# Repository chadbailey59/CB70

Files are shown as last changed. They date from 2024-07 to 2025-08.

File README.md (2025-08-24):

# CB70: A Split, Staggered Wireless Keyboard

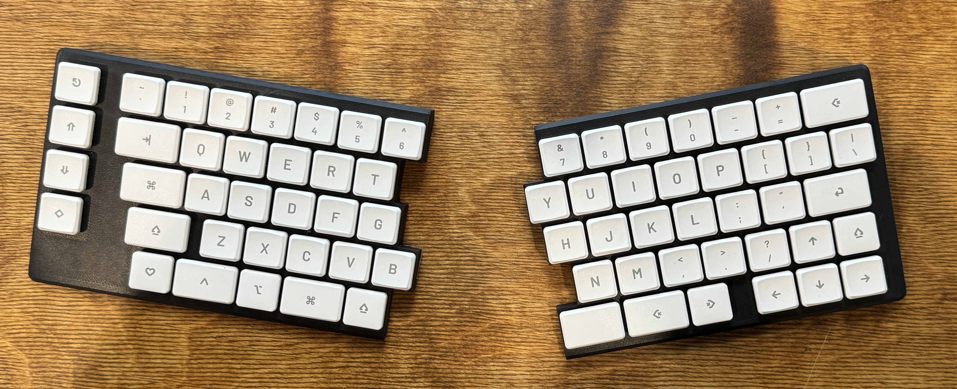
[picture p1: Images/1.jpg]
Low-Profile Choc Version


- Supports MX and Choc switches
- Dual-wireless, powered by Nice!Nano v2's and ZMK
- Compatible with lots of popular keysets

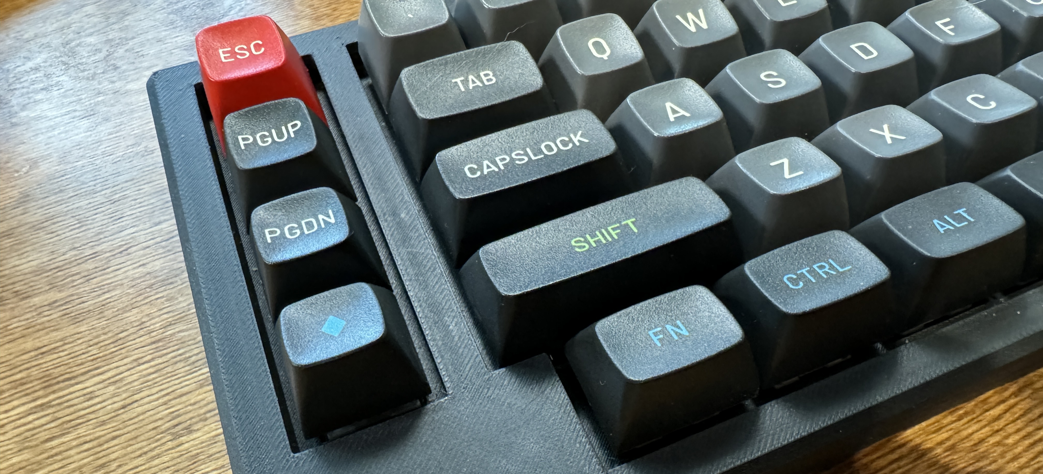
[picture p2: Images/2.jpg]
MX Version


Why CB70? It's my initials, and it used to be a 70-key layout. When I deleted a key, changing the name to The Joke Number just seemed too obvious.

## What's Available

- KiCAD files for the combo MX/Choc PCBs in `/PCB`
- [Keyboard Layout Editor](http://www.keyboard-layout-editor.com/) JSON for the MX and Choc versions in `/KLE`
- Config files for the ZMK firmware in `/ZMK`, and pre-compiled firmware in `/Firmware`
- OnShape docs for three different cases: [MX](https://cad.onshape.com/documents/61077a70c0807a2f741d218a/w/b756240a5bc81a242d3100ae/e/06f8d761157dde9586b0a508), [Choc](https://cad.onshape.com/documents/518ea40d790487622d23318b/w/b5c85f466e1f1d2c95445d69/e/3acfa7d78165eaa4fb25c29e), and [Choc Slim](https://cad.onshape.com/documents/839a1d1e7ccef3f6cb852ad6/w/885d6dd90bac1c92721256f6/e/4149e8558c641b31c0ba8e37)
- STL files for the 3 different case styles in `/Case`

### Update 2025-08-24: The Dongle Variant

ZMK recently added support for [dongles!](https://zmk.dev/docs/development/hardware-integration/dongle) There are now two versions of the firmware and ZMK source. The `non-dongle` folder is the traditional CB70, with two nice!nanos—one for the left half, one for the right. The `dongle` version actually requires _three_ nice!nanos (or whatever boards you're using): Two for the left and right halves, and one for the 'dongle'.

The main benefit of the dongle version (for me) is that it's easier to switch the whole keyboard to another computer by just plugging in the dongle.

## The Philosophy

The key layout is based around something I've been honing for almost five years now. I've tried a few different ortho/ergo layouts, but contrary to what the internet says, they always slow me down way too much. Meanwhile, I use this at my desk, I still use my MacBook Pro's built-in keyboard a lot, and I average 110-120 WPM on both.

A few thoughts on the layout:

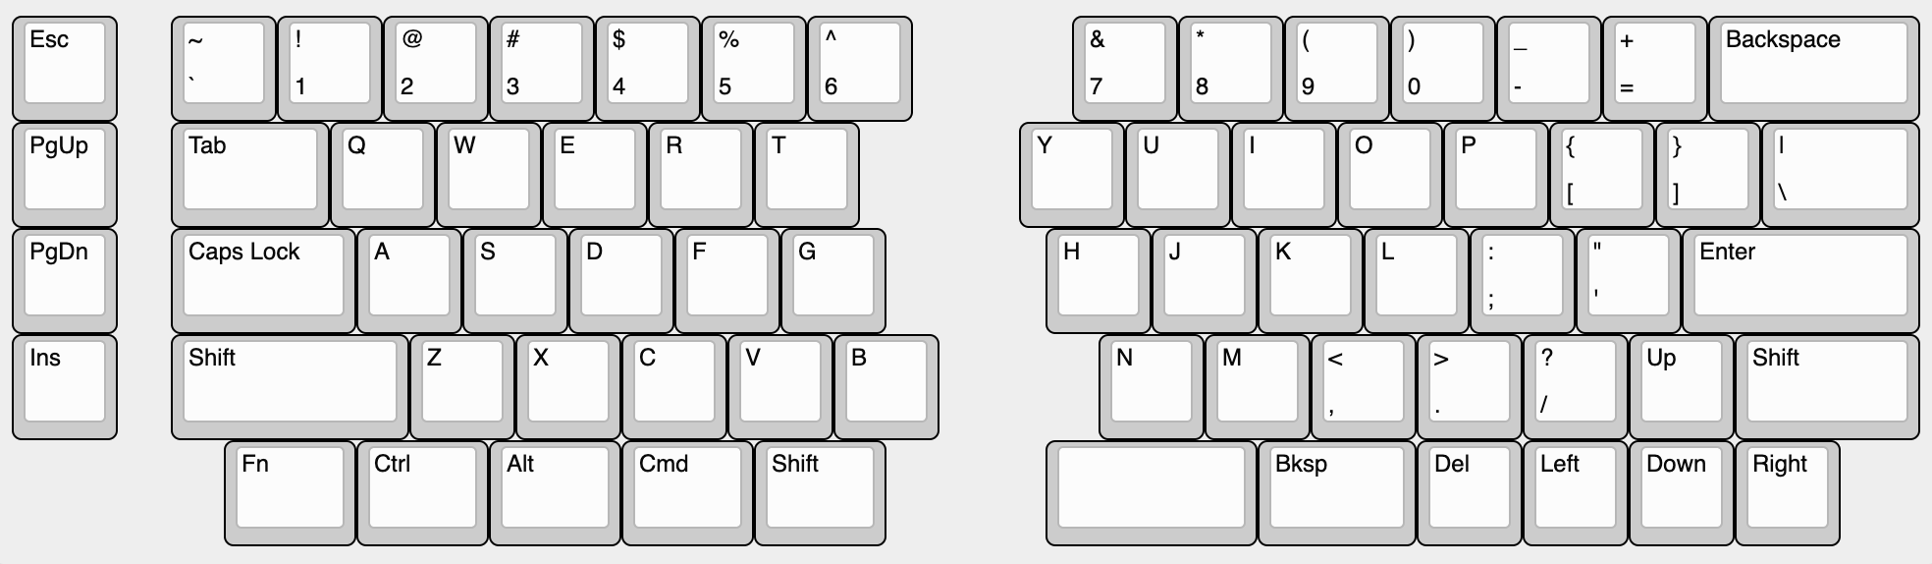
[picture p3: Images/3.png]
Key Layout


I wanted to maintain parity between my keyboard and my MacBook Pro's keyboard as much as possible, so I don't do much with ZMK itself. Rather, I use [Karabiner-elements](https://karabiner-elements.pqrs.org/) to make many of these 'tricks' work for both my custom keyboard and my MacBook Pro.

I've found I never use my left thumb for the space bar, so I placed a Shift key where my left thumb naturally falls. I fell in love with this almost immediately, and it's the first thing I miss when typing on my MacBook Pro. I've tried a few different Karabiner-elements hacks to attempt to replicate this for the MBP's built-in space bar, but none of them work that well.

I use the Caps Lock key as an additional Command key with my left pinky, which you'll see in the Choc keyset. That's remapped in Karabiner-elements so it works both places.

The bottom-left key is a "Function" key, but I use a Karabiner-elements complex modification called "Map Function to Hyper when held" to give me a bunch of custom shortcuts. I can't figure out how to share that directly here.

The bottom-right Backspace key is remapped to Option-Backspace, which deletes a word. This is maybe my single favorite thing I've ever done on a computer. If I'm writing in Slack and realize I want to reword the last few words I typed, it's a super quick way to delete a word at a time.

The left column gives me a dedicated Esc key, and the other three are remapped to volume up/down, and a play/pause key.

## Building Your Own

### Switches and Stabilizers

You'll need at least 69 switches, either 2-pin MX or Choc. If you use MX switches, you'll need 4 plate-mount stabilizers, [such as these](https://www.amazon.com/DUROCK-Stabilizer-Keyboard-Stabilizers-Compatible/dp/B0CRRHP9MY/). The Choc version doesn't use any stabilizers.

### Keycaps

You can get the same Choc keycaps you see in the picture from [FK Caps' Custom Shop](https://fkcaps.com/custom/1VP7N2) if you want.

For Choc switches, you'll need 60 1u keycaps, and 9 1.5u keycaps.

For MX switches, you should be able to get by with a pretty standard TKL or 70% keyset (that's by design). The only 'weird' keys are:

- 1.75u right Shift key
- 1.5u Backspace key in the bottom row
- 2u space bar
- 1.25u Shift key for your left thumb

The pictured MX version is the [MT3 Susuwatari keyset](https://drop.com/buy/drop-matt3o-mt3-susuwatari-custom-keycap-set?defaultSelectionIds=952681) from Drop, with the Base kit covering everything except the 2u space bar (which I added from the "Spacebars" kit).

### Other Supplies

- 12 [M3 x 4mm heat set inserts](https://www.amazon.com/gp/product/B09MCWTBCC)
- 12 M3 x 8mm screws
- 69 [1N4148 diodes](https://www.amazon.com/gp/product/B07Q4F3Y5W/ref=ppx_yo_dt_b_search_asin_title?ie=UTF8&psc=1)
- 2 [3.7V batteries with JST-PHR-02 connectors](https://www.amazon.com/gp/product/B08VRYS8FT)
- 6 [JST 2.0mm connectors for the PCB](https://www.amazon.com/Taiss-Connector-Housing-Connectors-F-066-580PCS/dp/B0BHT1FQGY). The PCBs are spaced for the 2mm JST connectors, which are sometimes also called JST-PHR-02, like on the linked batteries.
- 2 nice!nano v2 boards
- [These round pin headers](https://www.amazon.com/Uxcell-a14081900ux0270-Single-Straight-Header/dp/B012ACSO4Y) to socket the nice!nanos
- Most people use diode legs to socket the nice!nanos, but if you want nicer pins, [these are the only ones I've found](https://www.amazon.com/dp/B0CKYKRSZ6?ref=ppx_yo2ov_dt_b_product_details&th=1).
- Some [push button switches](https://www.amazon.com/dp/B085SWHFMK?psc=1&ref=ppx_yo2ov_dt_b_product_details) and
  [SPST slide switches](https://www.amazon.com/dp/B09R43HCY3?psc=1&ref=ppx_yo2ov_dt_b_product_details) for reset and power. These particular ones can be wired to JST connectors for case mounting, or soldered directly into the PCB for low-profile setups.

### Assembly

Assembly should be pretty straightforward if you've built a keyboard before. The PCBs are marked for diode orientation. You'll want to make sure to install all of the diodes and the nice!nano sockets before installing any of the keyswitches. I also needed to snip the nice!nano socket legs flush with the PCB so the keyswitches mounted flat.

See the ZMK instructions for using GitHub actions to build the firmware yourself if you want to edit the keymaps.

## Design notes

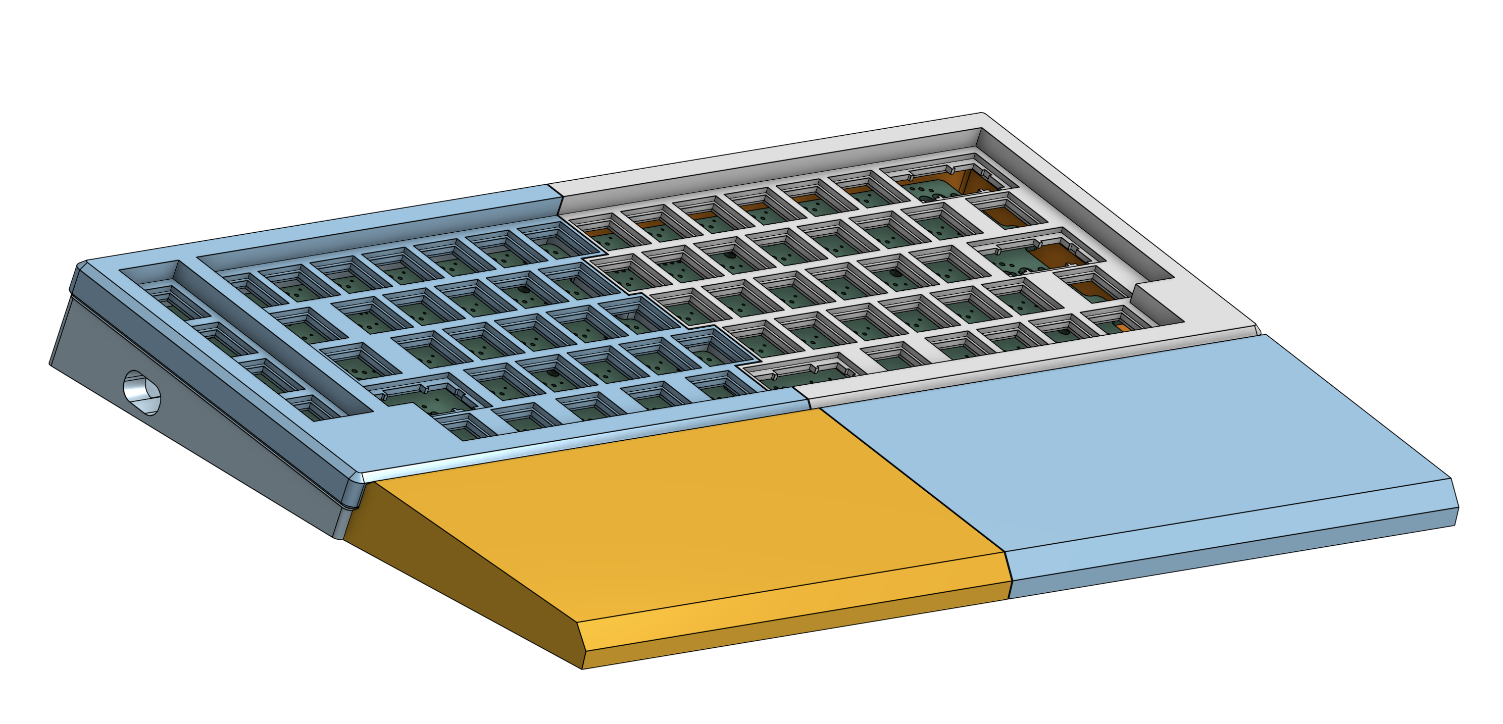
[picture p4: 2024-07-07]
Case/MX/pic.png

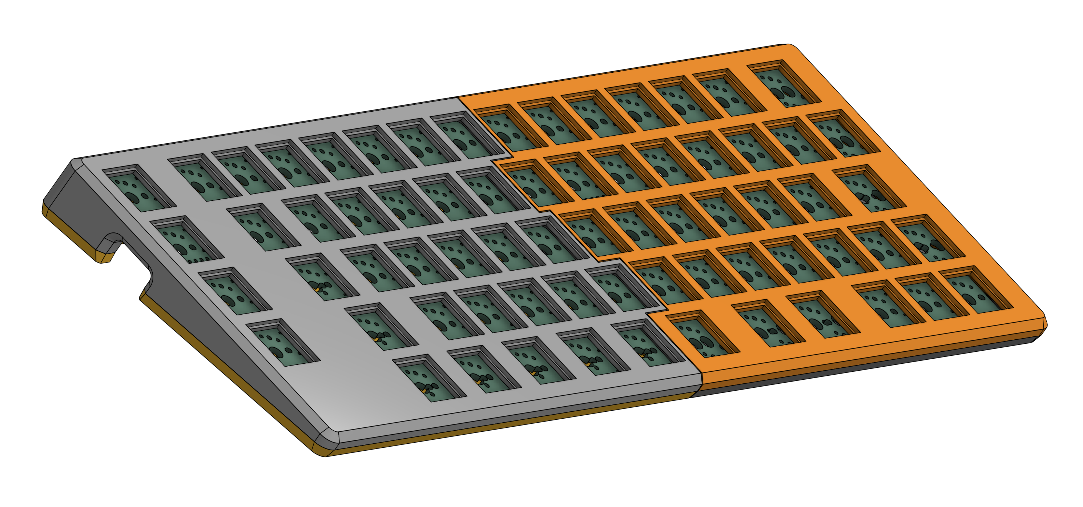
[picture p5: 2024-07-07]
Case/Choc-Slim/pic.png

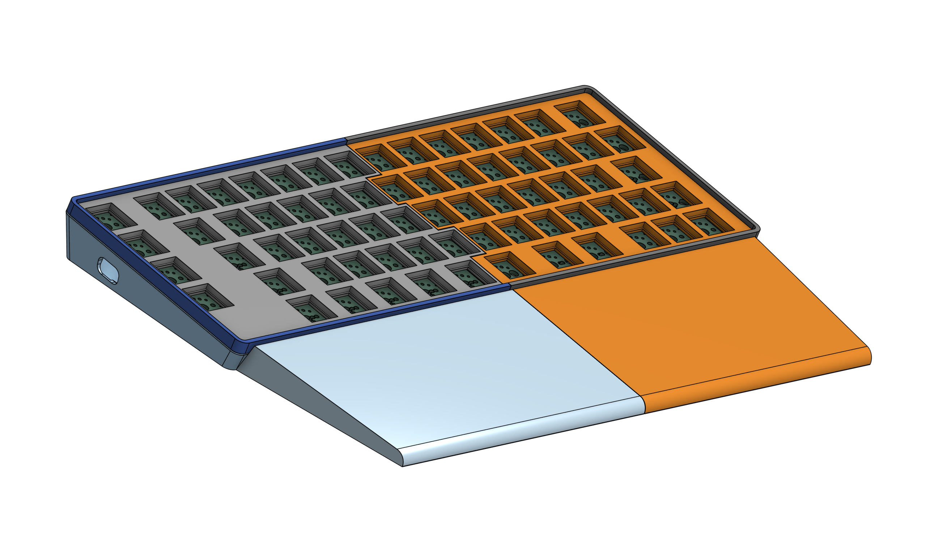
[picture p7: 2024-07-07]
Case/Choc/pic.png

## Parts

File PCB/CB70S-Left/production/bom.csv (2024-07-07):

Designator | Footprint | Quantity | Value | LCSC Part #
Batt1 | JST_PH_B2B-PH-K_1x02_P2.00mm_Vertical | 1 | B+
D_0, D_1, D_10, D_11, D_12, D_13, D_14, D_15, D_16, D_17, D_18, D_19, D_2, D_20, D_21, D_22, D_23, D_24, D_25, D_26, D_27, D_28, D_29, D_3, D_30, D_31, D_32, D_33, D_4, D_5, D_6, D_7, D_8, D_9 | Diode_DO-35 | 34 | D
K_0, K_1, K_10, K_11, K_12, K_13, K_14, K_15, K_17, K_18, K_19, K_2, K_20, K_21, K_22, K_24, K_25, K_26, K_27, K_28, K_29, K_3, K_31, K_33, K_4, K_5, K_6, K_7, K_8 | Choc-MX-19mm-1u | 29 | KEYSW
K_16, K_23, K_30, K_32, K_9 | Choc-MX-19mm-1.5u | 5 | KEYSW
K_16a1 | Choc-MX-19mm-1.75u | 1 | KEYSW
K_23a1 | Choc-MX-19mm-2.25u | 1 | KEYSW
K_34, K_35, K_36, K_37, K_38 | Choc-MX-19mm-1.25u | 5 | KEYSW
SW1 | JST_PH_B2B-PH-K_1x02_P2.00mm_Vertical | 1 | POWER
SW2 | JST_PH_B2B-PH-K_1x02_P2.00mm_Vertical | 1 | RESET
U1 | nice_nano | 1 | nice_nano

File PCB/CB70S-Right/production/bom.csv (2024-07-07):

Designator | Footprint | Quantity | Value | LCSC Part #
BAT1 | JST_PH_B2B-PH-K_1x02_P2.00mm_Vertical | 1 | B-
D_0, D_1, D_10, D_11, D_12, D_13, D_14, D_15, D_16, D_17, D_18, D_19, D_2, D_20, D_21, D_22, D_23, D_24, D_25, D_26, D_27, D_28, D_29, D_3, D_30, D_31, D_32, D_33, D_34, D_4, D_5, D_6, D_7, D_8, D_9 | Diode_DO-35 | 35 | D
K_0, K_1, K_10, K_11, K_12, K_13, K_14, K_15, K_16, K_17, K_18, K_19, K_2, K_20, K_22, K_23, K_24, K_25, K_26, K_27, K_28, K_3, K_31, K_32, K_33, K_34, K_37, K_4, K_5, K_7, K_8, K_9 | Choc-MX-19mm-1u | 32 | KEYSW
K_21, K_29, K_30, K_36, K_39, K_6 | Choc-MX-19mm-1.5u | 6 | KEYSW
K_35, K_38 | Choc-MX-19mm-2u | 2 | KEYSW
K_40 | Choc-MX-19mm-2.25u | 1 | KEYSW
K_41 | Choc-MX-19mm-1.75u | 1 | KEYSW
PWR1, RST1 | JST_PH_B2B-PH-K_1x02_P2.00mm_Vertical | 2 | SW_SPST
U1 | nice_nano_no_mid | 1 | nice_nano

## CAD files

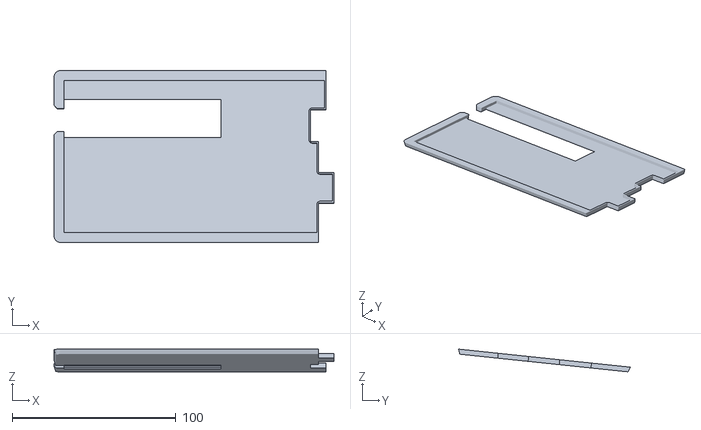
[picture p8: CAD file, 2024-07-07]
Case/Choc-Slim/Choc-Slim - Left Base.stl
171.1 x 105.0 x 13.9

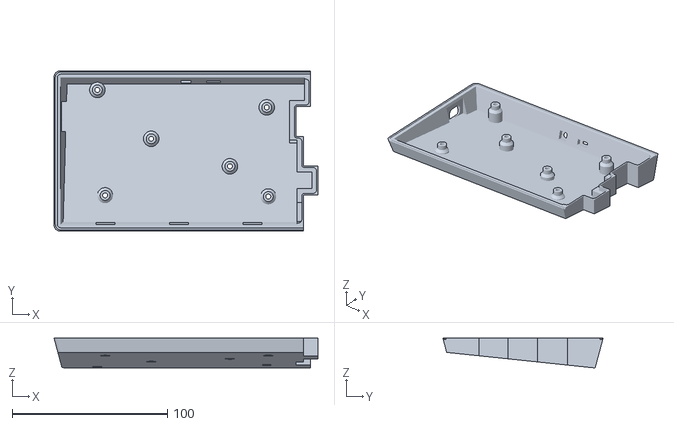
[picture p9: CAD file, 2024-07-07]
Case/Choc/Choc - Left Base.stl
170.3 x 103.4 x 19.3

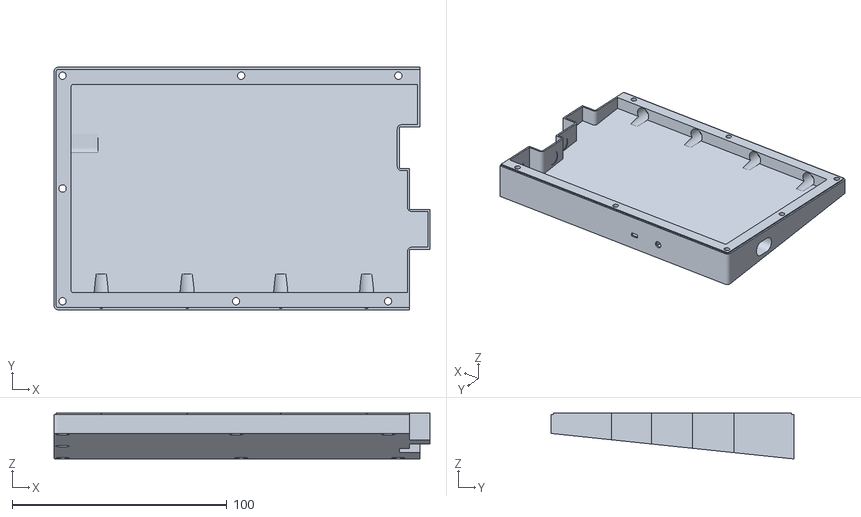
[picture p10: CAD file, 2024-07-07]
Case/MX/MX - Left Base.stl
175.1 x 113.0 x 21.4

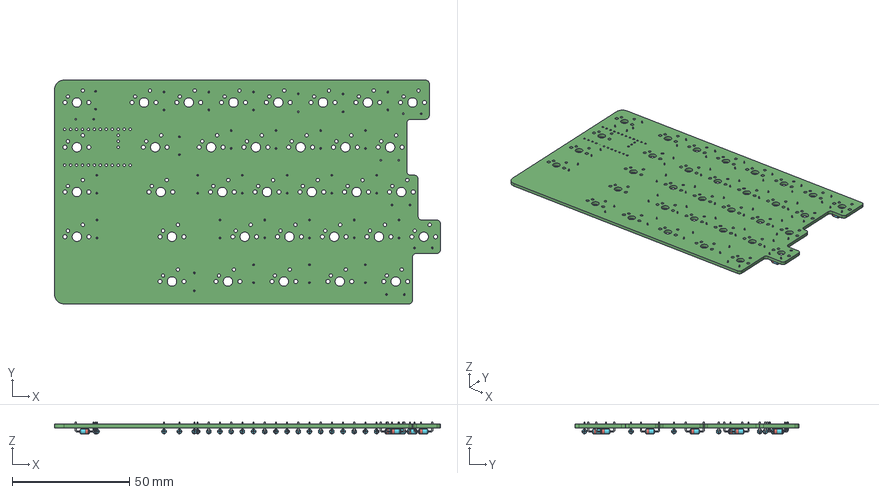
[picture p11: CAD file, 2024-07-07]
PCB/CB70S-Left/keyboard.step
164.3 x 95.2 x 5.01 mm

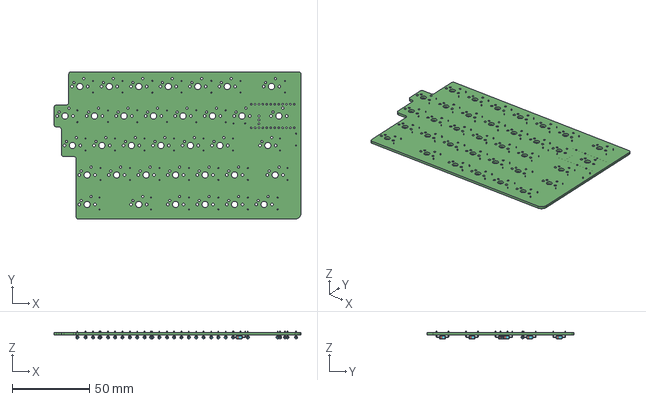
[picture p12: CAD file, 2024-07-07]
PCB/CB70S-Right/keyboard.step
159.5 x 95.2 x 5.01 mm

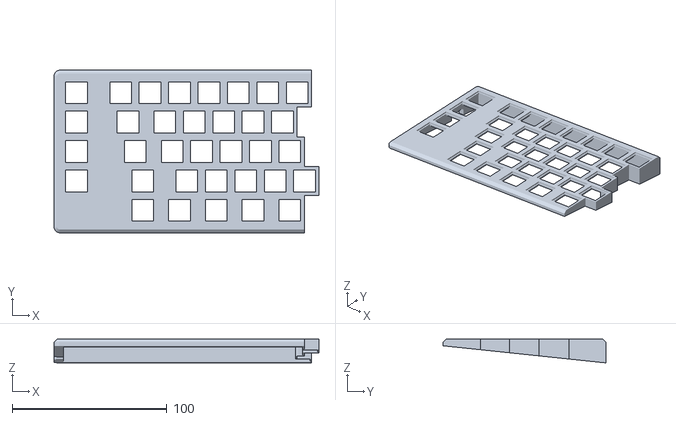
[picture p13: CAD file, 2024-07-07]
Case/Choc-Slim/Choc-Slim - Left Plate.stl
171.1 x 105.0 x 15.4

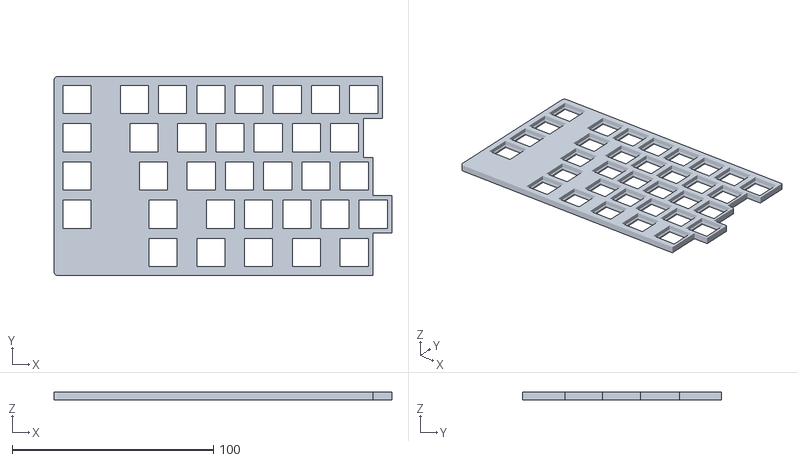
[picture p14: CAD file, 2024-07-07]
Case/Choc/Choc - Left Plate.stl
168.1 x 99.0 x 3.80

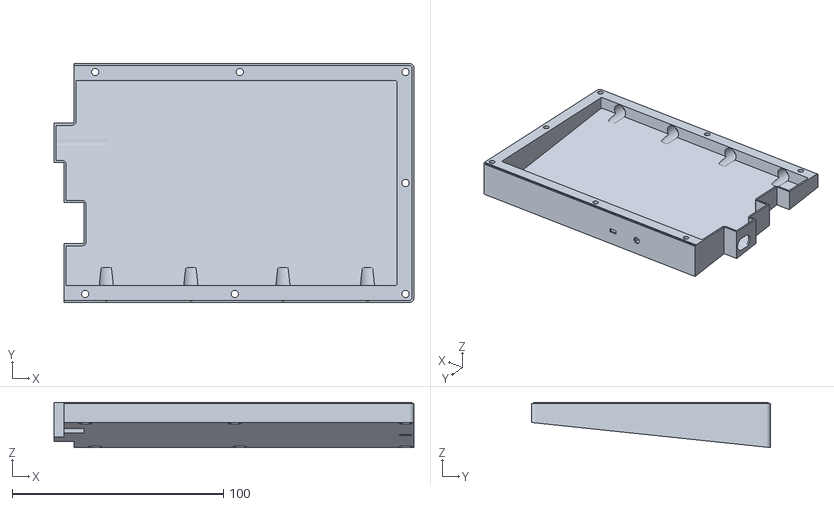
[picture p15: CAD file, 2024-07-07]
Case/MX/MX - Right Base.stl
170.3 x 113.0 x 21.4

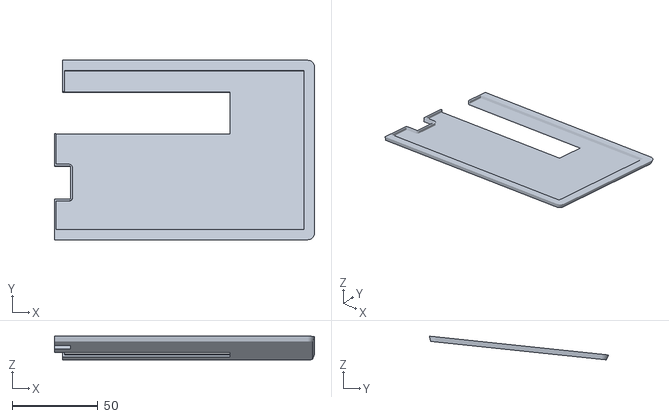
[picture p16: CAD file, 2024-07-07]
Case/Choc-Slim/Choc-Slim - Right Base.stl
152.1 x 105.0 x 13.9

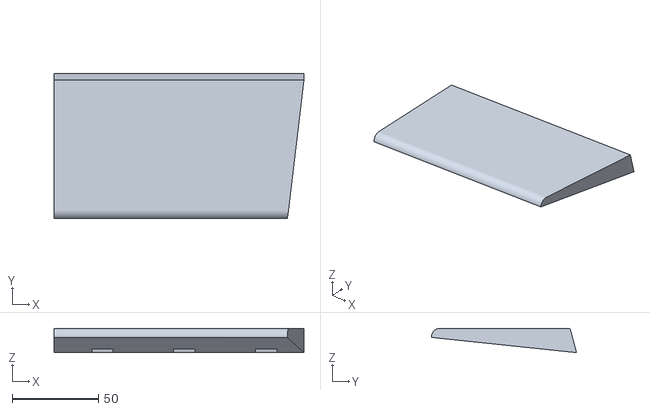
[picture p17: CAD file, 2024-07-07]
Case/Choc/Choc - Right Wrist Rest.stl
144.7 x 84.0 x 14.1

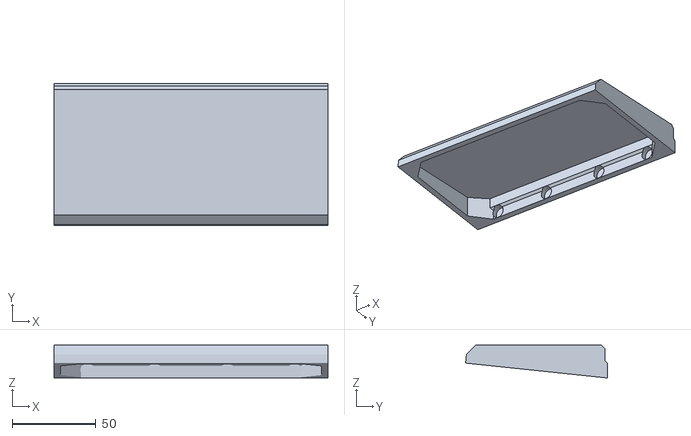
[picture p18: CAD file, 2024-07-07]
Case/MX/MX - Right Wrist Rest.stl
163.6 x 84.7 x 19.7

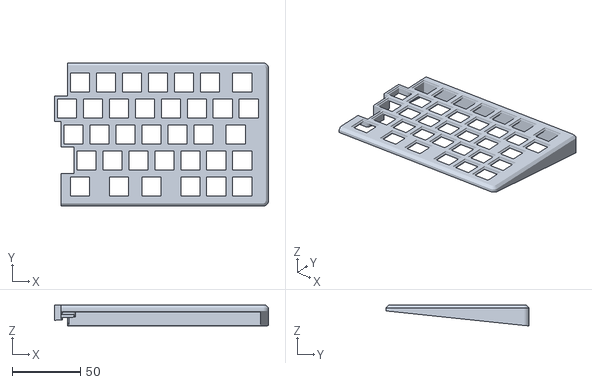
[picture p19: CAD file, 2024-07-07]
Case/Choc-Slim/Choc-Slim - Right Plate.stl
156.8 x 105.0 x 15.4

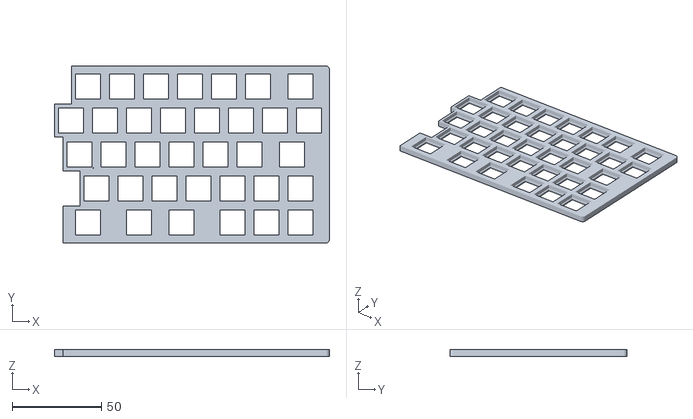
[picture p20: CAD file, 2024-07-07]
Case/Choc/Choc - Right Plate.stl
153.8 x 99.0 x 3.80

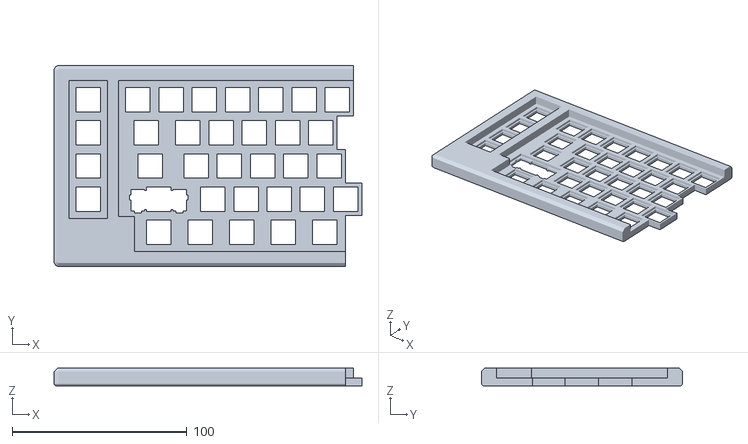
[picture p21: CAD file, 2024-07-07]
Case/MX/MX - Left Top.stl
176.1 x 115.0 x 10.2

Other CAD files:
Case/Choc/Choc - Left Wrist Rest.stl
Case/MX/MX - Right Top.stl
Case/Choc/Choc - Left Top.stl
Case/MX/MX - Left Wrist Rest.stl
Case/Choc/Choc - Right Top.stl
Case/Choc/Choc - Right base.stl

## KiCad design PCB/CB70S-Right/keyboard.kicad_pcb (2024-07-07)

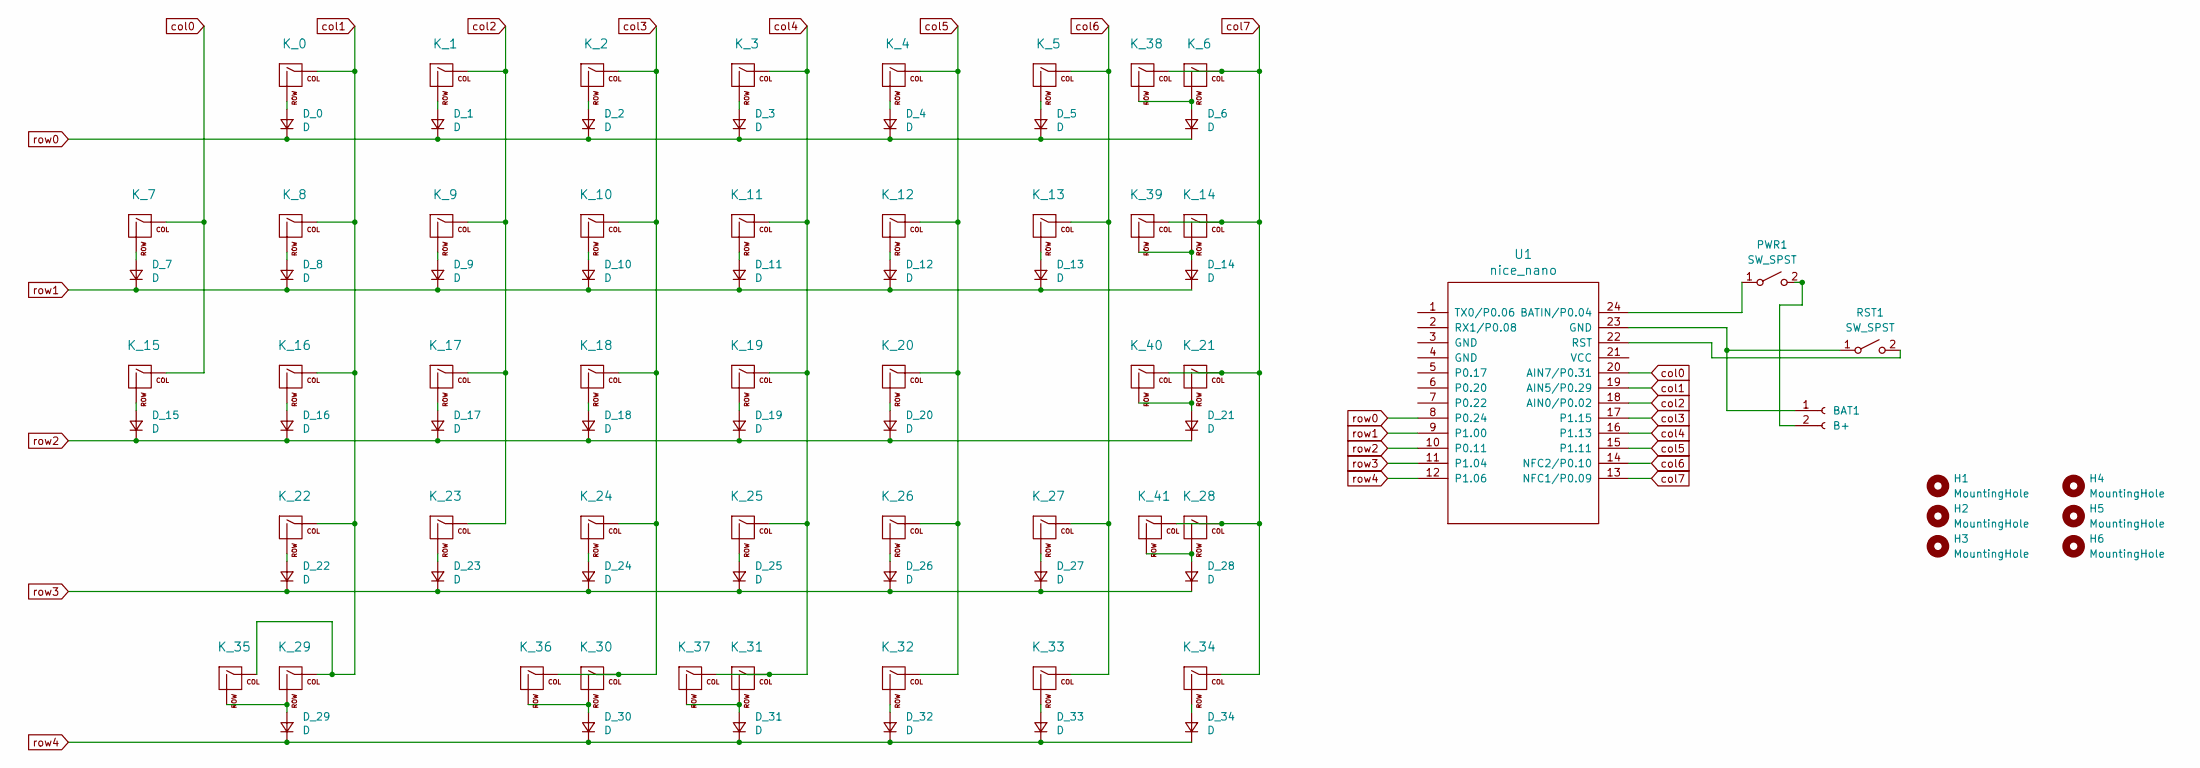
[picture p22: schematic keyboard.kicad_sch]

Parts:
BAT1: B+; JST_PH_B2B-PH-K_1x02_P2.00mm_Vertical
D_0, D_1, D_2, D_3, D_4, D_5, D_6, D_7, D_8, D_9, D_10, D_11, D_12, D_13, D_14, D_15, D_16, D_17, D_18, D_19, D_20, D_21, D_22, D_23, D_24, D_25, D_26, D_27, D_28, D_29, D_30, D_31, D_32, D_33, D_34: D; Diode_DO-35
H1, H2, H3, H4, H5, H6: MountingHole; MountingHole_3.2mm_M3
K_0, K_1, K_2, K_3, K_4, K_5, K_7, K_8, K_9, K_10, K_11, K_12, K_13, K_14, K_15, K_16, K_17, K_18, K_19, K_20, K_22, K_23, K_24, K_25, K_26, K_27, K_28, K_31, K_32, K_33, K_34, K_37: KEYSW; Choc-MX-19mm-1u
K_6, K_21, K_29, K_30, K_36, K_39: KEYSW; Choc-MX-19mm-1.5u
K_35, K_38: KEYSW; Choc-MX-19mm-2u
K_40: KEYSW; Choc-MX-19mm-2.25u
K_41: KEYSW; Choc-MX-19mm-1.75u
PWR1: SW_SPST; JST_PH_B2B-PH-K_1x02_P2.00mm_Vertical
RST1: SW_SPST; JST_PH_B2B-PH-K_1x02_P2.00mm_Vertical
U1: nice_nano; nice_nano_no_mid

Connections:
unnamed: BAT1.1, RST1.1 (A), U1.23 (GND)
unnamed: BAT1.2, PWR1.2 (B)
unnamed: D_0.2 (A), K_0.2 (ROW)
unnamed: D_1.2 (A), K_1.2 (ROW)
unnamed: D_2.2 (A), K_2.2 (ROW)
unnamed: D_3.2 (A), K_3.2 (ROW)
unnamed: D_4.2 (A), K_4.2 (ROW)
unnamed: D_5.2 (A), K_5.2 (ROW)
unnamed: D_6.2 (A), K_6.2 (ROW), K_38.2 (ROW)
unnamed: D_7.2 (A), K_7.2 (ROW)
unnamed: D_8.2 (A), K_8.2 (ROW)
unnamed: D_9.2 (A), K_9.2 (ROW)
unnamed: D_10.2 (A), K_10.2 (ROW)
unnamed: D_11.2 (A), K_11.2 (ROW)
unnamed: D_12.2 (A), K_12.2 (ROW)
unnamed: D_13.2 (A), K_13.2 (ROW)
unnamed: D_14.2 (A), K_14.2 (ROW), K_39.2 (ROW)
unnamed: D_15.2 (A), K_15.2 (ROW)
unnamed: D_16.2 (A), K_16.2 (ROW)
unnamed: D_17.2 (A), K_17.2 (ROW)
unnamed: D_18.2 (A), K_18.2 (ROW)
unnamed: D_19.2 (A), K_19.2 (ROW)
unnamed: D_20.2 (A), K_20.2 (ROW)
unnamed: D_21.2 (A), K_21.2 (ROW), K_40.2 (ROW)
unnamed: D_22.2 (A), K_22.2 (ROW)
unnamed: D_23.2 (A), K_23.2 (ROW)
unnamed: D_24.2 (A), K_24.2 (ROW)
unnamed: D_25.2 (A), K_25.2 (ROW)
unnamed: D_26.2 (A), K_26.2 (ROW)
unnamed: D_27.2 (A), K_27.2 (ROW)
unnamed: D_28.2 (A), K_28.2 (ROW), K_41.2 (ROW)
unnamed: D_29.2 (A), K_29.2 (ROW), K_35.2 (ROW)
unnamed: D_30.2 (A), K_30.2 (ROW), K_36.2 (ROW)
unnamed: D_31.2 (A), K_31.2 (ROW), K_37.2 (ROW)
unnamed: D_32.2 (A), K_32.2 (ROW)
unnamed: D_33.2 (A), K_33.2 (ROW)
unnamed: D_34.2 (A), K_34.2 (ROW)
unnamed: PWR1.1 (A), U1.24 (BATIN/P0.04)
unnamed: RST1.2 (B), U1.22 (RST)
col0: K_7.1 (COL), K_15.1 (COL), U1.20 (AIN7/P0.31)
col1: K_0.1 (COL), K_8.1 (COL), K_16.1 (COL), K_22.1 (COL), K_29.1 (COL), K_35.1 (COL), U1.19 (AIN5/P0.29)
col2: K_1.1 (COL), K_9.1 (COL), K_17.1 (COL), K_23.1 (COL), U1.18 (AIN0/P0.02)
col3: K_2.1 (COL), K_10.1 (COL), K_18.1 (COL), K_24.1 (COL), K_30.1 (COL), K_36.1 (COL), U1.17 (P1.15)
col4: K_3.1 (COL), K_11.1 (COL), K_19.1 (COL), K_25.1 (COL), K_31.1 (COL), K_37.1 (COL), U1.16 (P1.13)
col5: K_4.1 (COL), K_12.1 (COL), K_20.1 (COL), K_26.1 (COL), K_32.1 (COL), U1.15 (P1.11)
col6: K_5.1 (COL), K_13.1 (COL), K_27.1 (COL), K_33.1 (COL), U1.14 (NFC2/P0.10)
col7: K_6.1 (COL), K_14.1 (COL), K_21.1 (COL), K_28.1 (COL), K_34.1 (COL), K_38.1 (COL), K_39.1 (COL), K_40.1 (COL), K_41.1 (COL), U1.13 (NFC1/P0.09)
row0: D_0.1 (K), D_1.1 (K), D_2.1 (K), D_3.1 (K), D_4.1 (K), D_5.1 (K), D_6.1 (K), U1.8 (P0.24)
row1: D_7.1 (K), D_8.1 (K), D_9.1 (K), D_10.1 (K), D_11.1 (K), D_12.1 (K), D_13.1 (K), D_14.1 (K), U1.9 (P1.00)
row2: D_15.1 (K), D_16.1 (K), D_17.1 (K), D_18.1 (K), D_19.1 (K), D_20.1 (K), D_21.1 (K), U1.10 (P0.11)
row3: D_22.1 (K), D_23.1 (K), D_24.1 (K), D_25.1 (K), D_26.1 (K), D_27.1 (K), D_28.1 (K), U1.11 (P1.04)
row4: D_29.1 (K), D_30.1 (K), D_31.1 (K), D_32.1 (K), D_33.1 (K), D_34.1 (K), U1.12 (P1.06)

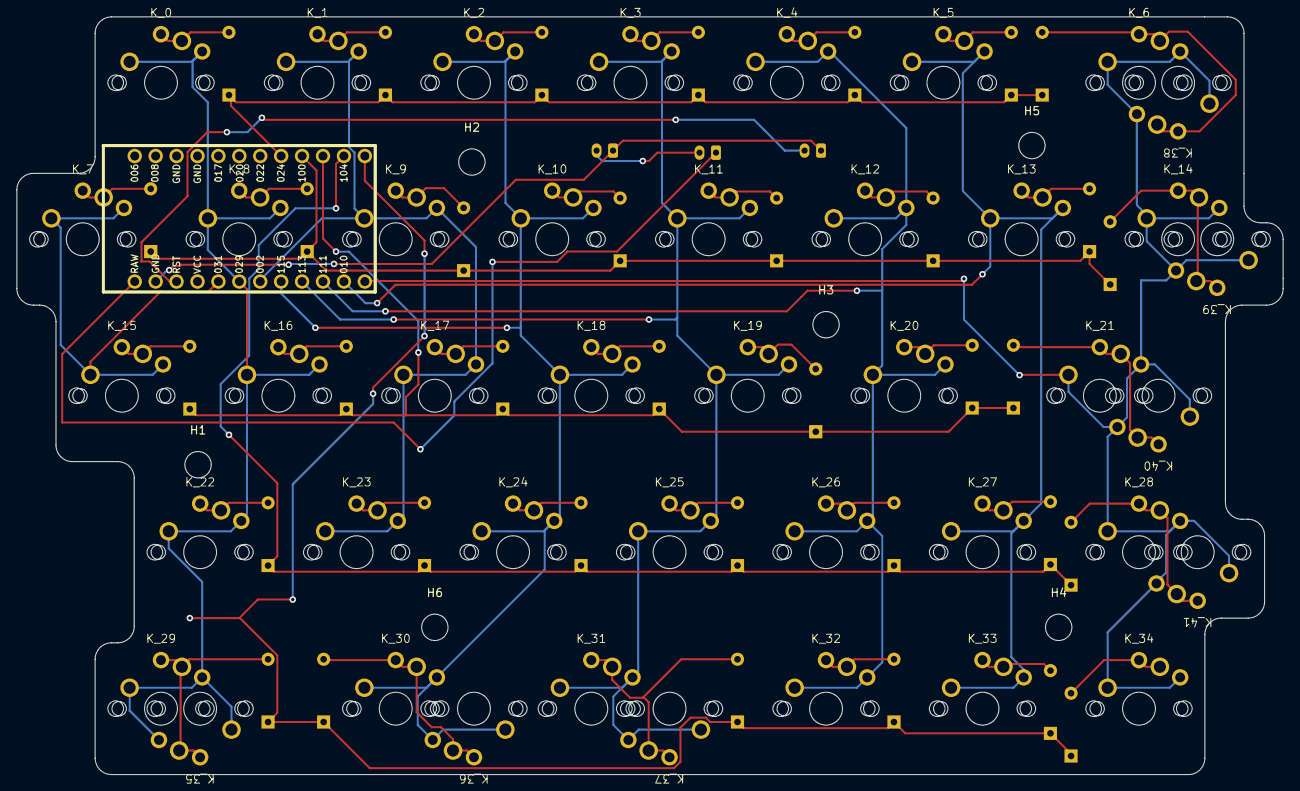
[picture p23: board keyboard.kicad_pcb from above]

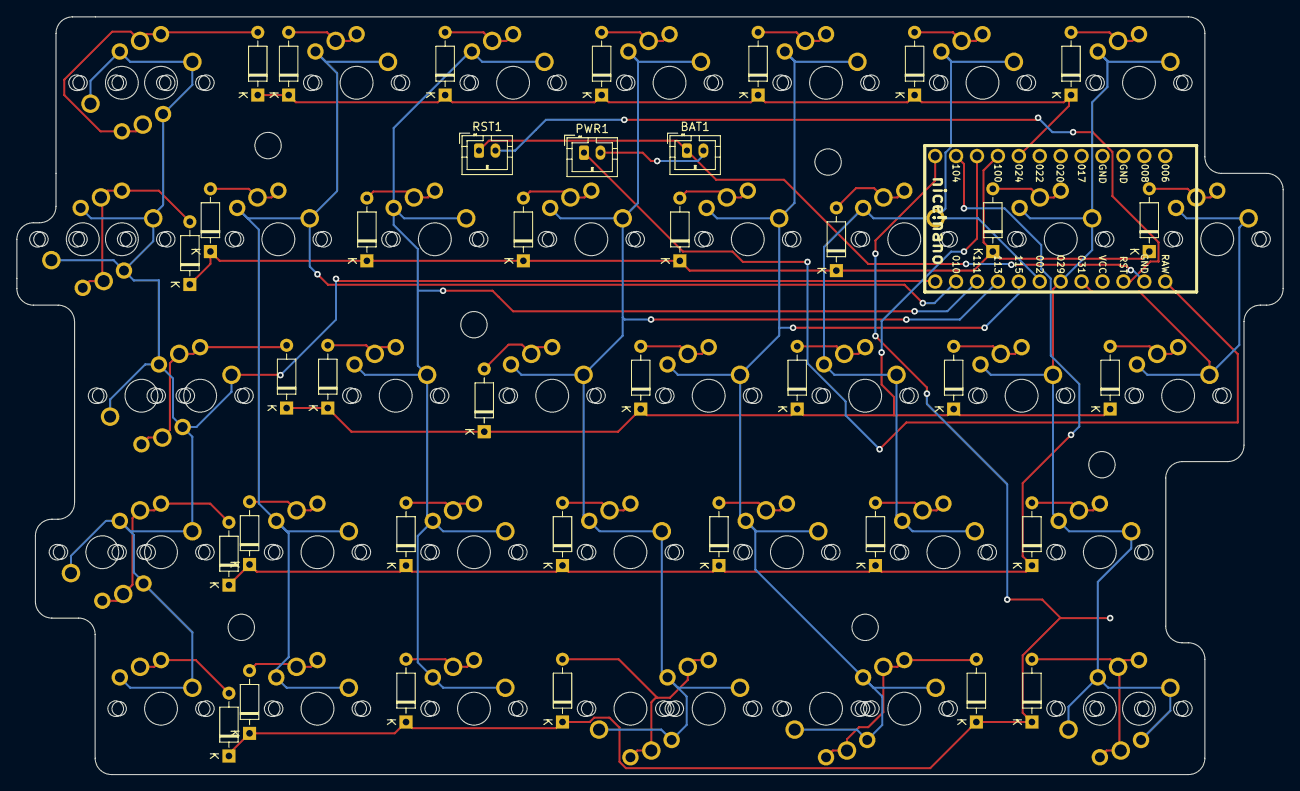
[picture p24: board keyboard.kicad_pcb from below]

Board: 2 copper layers, 153.8 x 92.0 mm, 87 parts (39 on the bottom side), 52 nets.

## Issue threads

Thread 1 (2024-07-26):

How to connect the power switch

tangbonze, 2024-07-26:
Could you please explain a little bit how to connect the power switch. I noticed that the switch on the PCB has two pins, but the switch has three pins. Thanks a lot.

chadbailey59, 2024-07-26:
Sure! The simplest thing would be to use a single-pole, single-throw (SPST) switch, which only has two pins. In that case, you solder either pin to either terminal. The switch I mentioned is a single-pole, double-throw (SPDT) switch; I just snipped one of the outer legs to turn it into an SPST switch.

Closed 2024-07-26.
